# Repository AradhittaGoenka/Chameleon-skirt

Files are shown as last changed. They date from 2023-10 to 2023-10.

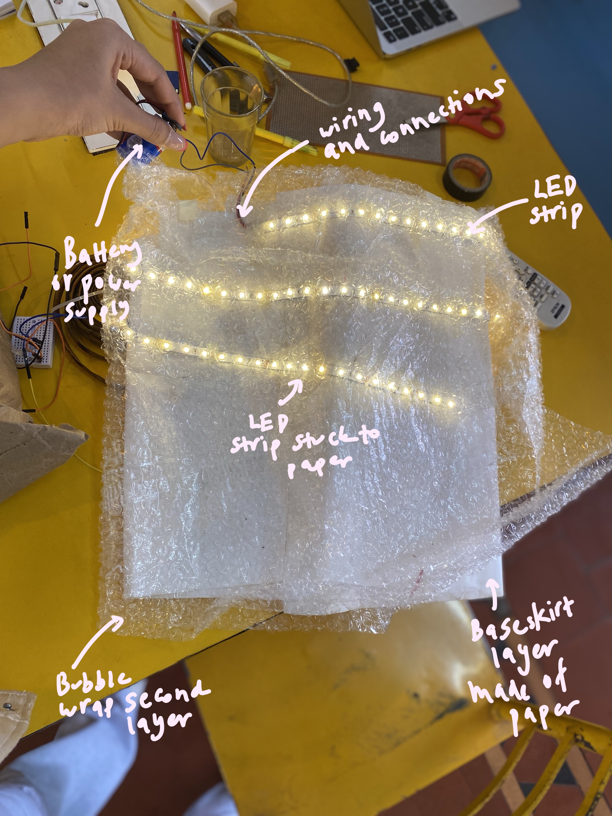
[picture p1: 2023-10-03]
Source files/Images/Labelled paper prototype.jpg

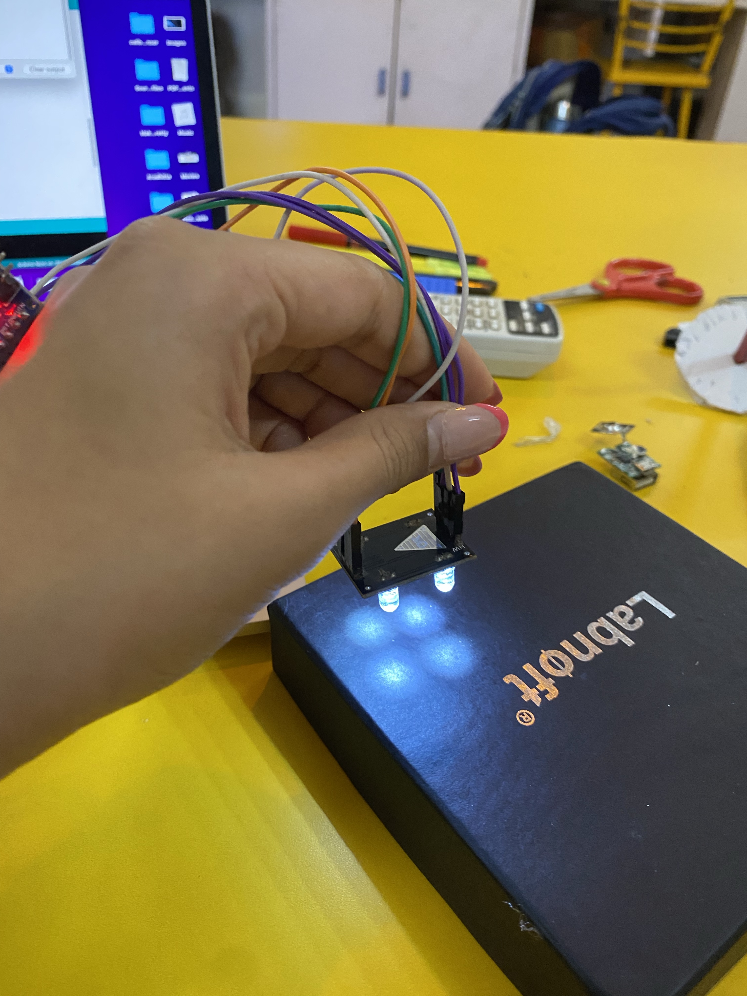
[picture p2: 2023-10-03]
Source files/Images/Colour sensor black calibration.jpg.jpg

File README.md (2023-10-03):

**Spreading joy- A skirt**

**Description:** A fun skirt that changes colour when you hug someone and becomes the colour of their clothing, and lights up in different colours.
Using LEDs that make the skirt light up and a colour sensor to make the skirt change colour!

**Idea:** My idea was to create a fun project that allows you to change the colour of your skirt when you hug someone. I wanted combine fashion and electronics in a fun way that allows people to enjoy and interact with their clothing. Additionally the projects aims to spread love and happiness by encouraging people to hug others and simply make people smile by this simple act.

**Prototypes and rejected versions:**
Problems I faced- my colour sensor needed to be on the outside of the skirt as for it to detect colour it needs to have no obstacles obstructing its view, however, it also has to look nice and the wires or the colour sensor cannot directly be visible. Secondly, the colour sensor needed to be surrounded by some sort of housing so that it did not detect the colour of the skirt itself or have any other interference. My initial models did not have a housing for the colour sensor so the values predicted it by it were not accurate. The RGB strip also needed to be cut and each individual piece soldered to the next which was a time consuming and difficult task. A 12V battery supply was also too large to fit a portable light skirt that you can dance in, but all the long RGB strips were only powered by a 12V power supply. Additionally, I struggled a lot with calibrating my colour sensor and ensuring it can detect the colours in my surroundings.

**Paper prototype:**
For my paper prototype, I wanted to see how I would place the led strip on the skirt, and I wanted to try seeing where all my wiring would go so that it would not hurt the person wearing the skirt and would not be visible. I also wanted to see how I could hide the LED strip so that I could ensure the person wearing it had a fashionable skirt. I thus came up with the idea of having 2 layers for my skirt, the first inner layer where the LED strip was secured and the second outer translucent later that allows the light to pass through while covering the LED strip and also houses the sensor. The bubble wrap does this in the prototype and theres a small inner pocket that houses all the wiring in the skirt.
Solutions and changes: To ensure my colour sensor is on the outside of the skirt and can detect different colours, I came up with the idea of making a second translucent outer layer to my skirt that can hold the colour sensor easily and still look nice. Then to solve the problem of housing my colour sensor I 3d printed a case for my colour sensor that ensures no other colours can interfere with it and affect it. Then to ensure I didn’t have to solder each individual RBG strip to a belt at the top of the skirt, we decided to connect the RBG strips to each other using wires. We also decided that a 9V battery would be good enough to power a 12V RGB strip and it would still glow brightly and be portable.

**Objectives of the project:**
Detect the colour of the surroundings easily
Change the colour of the skirt according to the detected colour of the surroundings Have a skirt that looks cool and changes colour

**Materials: **
Skirt :
A plain straight skirt
An outer translucent skirt
Fabric glue or fevikwik
Thread and a small stiching set, including scissor

LED strip:
10m total RBG LED strip - https://www.amazon.in/Protium-Lights-Multi-Colors-waterproof-Controller/dp/B08YKBRSB4/ref=sr_1_11? crid=3LQOJ6J16MNGD&keywords=rgb+neopixel+led+strip&qid=1696230770&sprefix=rbg+neopixel+led+strip%2Caps%2C191&sr=8-11      
Wires
Soldering iron

Colour sensing:
tcs 3200 colour sensor- https://www.amazon.in/Robodo-Electronics-SEN41-Recognition-Detector/dp/B0787N1L24/ref=sr_1_2? crid=332Y5Y5U4F87S&keywords=colour+sensor+for+arduino&qid=1696230879&sprefix=colour+sensor+%2Caps%2C194&sr=8-2
3d printed and designed enclosure or housing

Power supply:
Rechargeable Batteries (9V)- https://www.amazon.in/Envie-2xC-Size-Rechargeable-Batteries/dp/B00BOLC962/ref=sr_1_1_sspa? crid=8MHD2RY7D6UC&keywords=9v+rechargeable+battery&qid=1696230562&sprefix=9V+rechargeable+batter%2Caps%2C213&sr=8- 1-spons&sp_csd=d2lkZ2V0TmFtZT1zcF9hdGY&psc=1
Charging Module- https://www.amazon.in/Charger-Charge-Control-Rechargeable-Batteries/dp/B0BCG3W4L5/ref=sr_1_1? crid=1IOIABLJQ45KZ&keywords=9v+rechargeable+battery+charger&qid=1696230614&sprefix=9v+rechargeable+battery+cha%2Caps%2C 1
Power Convertor if using less than 9V or if using 5V (the dress will not be portable if this is used

Controller:
Arduino nano - https://www.amazon.in/Maison-Nano-Board-CH340-ATmega328P/dp/B0C1H271SP/ref=sr_1_5? crid=2E5Y3JJTCRWWO&keywords=arduino+nano&qid=1696230648&sprefix=ardui%2Caps%2C207&sr=8-5

**Skills used in the project:**
Throughout the course of this project I learnt a variety of skills and was able to apply a lot of the skills I learnt in both the online and offline sessions at the asylum. I got to work a lot with arduino which helped reinforce all the skills I learnt in the electronics session. I also got to use C while coding the arduino to work and this further strengthened my coding skills. I also worked a lot on my soldering skills which helped me become much better at soldering and more comfortable with all the tools. Additionally, all the CAD sessions were very helpful while designing the case for the colour sensor and I also learnt how to 3d print and design 3d prints. Additionally, all the guidance and support of all our mentors made this project possible and I also learnt many new skills through it like troubleshooting and using a multimeter.
Working of Individual blocks:
The first block was the colour sensor. To test the colour sensor, first you needed to calibrate the colour sensor using a black paper and a white paper. Then once the colour sensor was calibrated we put the minimum and maximum RGB values into the code that runs the colour sensor, this code gave us RGB values. This allowed me to test the colour sensor. We then tried connecting the sensor to an RBG led to see how this was working. The second block was the RGB led strip, this has to be cut to the length of the skirt and then soldered to each other. Then we tested out the working of the strip using a power and supply.

**Logic of the complete program:**
1. When you hug someone, the colour sensor identifies the colour of their clothing and reads the RBG values. 2. These RGB values are then transferred onto the RBG LED strip which changes colour according to this.
3. All the LEDs then change colour and become a certain colour making your dress change colour.
In the end we connected the two blocks to make the final skirt which changes colours, spreading more hugs.
Assembly:
To assemble the skirt, first take the skirt and measure the lengths and distances at which you want to space the led strips. Then cut the LED strips according to the length and cut wires according to the distance between LED strips. Then solder the strips and wires together to form a long connected strip. Then connect the led strip to the arduino and colour sensor and to the power supply. Then stick the strips onto the skirt, and place all the wiring except for the colour sensor in an inner pocket in the skirt. Then place the colour sensor on the center of the outter skirt and stick it there. The skirt is now ready.

**References and sources:**

For inspiration on design and ideas:
https://learn.adafruit.com/florabrella/overview
https://learn.adafruit.com/chameleon-scarf

For help with the code and troubleshooting:
https://dnschecker.org/convert-rgb-to-pantone-pms.php 
https://dronebotworkshop.com/arduino-color-sense/
https://www.youtube.com/watch?v=uczaIETo_Jg 
https://randomnerdtutorials.com/arduino-color-sensor-tcs230-tcs3200/
https://github.com/nthnn/TCS3200

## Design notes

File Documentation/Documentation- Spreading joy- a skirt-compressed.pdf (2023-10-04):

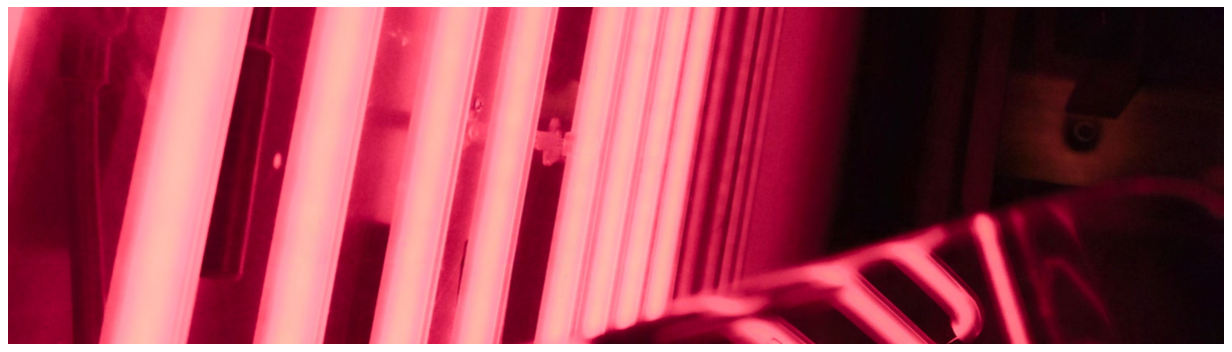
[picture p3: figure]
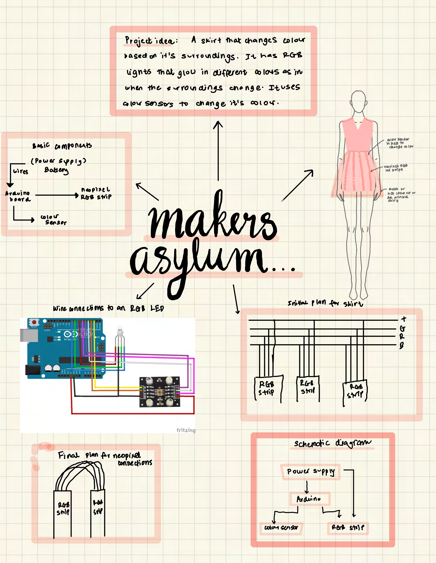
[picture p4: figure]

Documentation- Spreading joy- a skirt | 1

# Documentation- Spreading joy- a skirt

Description: A fun skirt that changes colour when you hug someone and becomes the colour of their clothing, and lights up in different colours. Using LEDs that make the skirt light up and a colour sensor to make the skirt change colour!

Idea: My idea was to create a fun project that allows you to change the colour of your skirt when you hug someone. I wanted combine fashion and electronics in a fun way that allows people to enjoy and interact with their clothing. Additionally the projects aims to spread love and happiness by encouraging people to hug others and simply make people smile by this simple act.

Prototypes and rejected versions:
Problems I faced- my colour sensor needed to be on the outside of the skirt as for it to detect colour it needs to have no obstacles obstructing its view, however, it also has to look nice and the wires or the colour sensor cannot directly be visible. Secondly, the colour sensor needed to be surrounded by some sort of housing so that it did not detect the colour of the skirt itself or have any other interference. My initial models did not have a housing for the colour sensor so the values predicted it by it were not accurate. The RGB strip also needed to be cut and each individual piece soldered to the next which was a time consuming and difficult task. A 12V battery supply was also too large to fit a portable light skirt that you can dance in, but all the long RGB strips were only powered by a 12V power supply. Additionally, I struggled a lot with calibrating my colour sensor and ensuring it can detect the colours in my surroundings.

Ideation and planning my project:

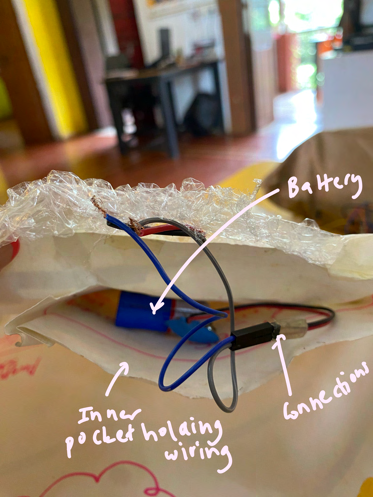
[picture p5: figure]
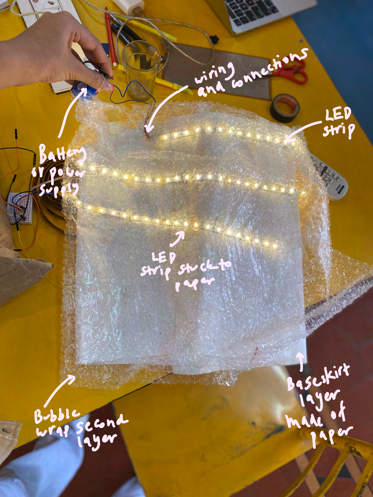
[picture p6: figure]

Documentation- Spreading joy- a skirt | 2

Paper prototype:
For my paper prototype, I wanted to see how I would place the led strip on the skirt, and I wanted to try seeing where all my wiring would go so that it would not hurt the person wearing the skirt and would not be visible. I also wanted to see how I could hide the LED strip so that I could ensure the person wearing it had a fashionable skirt. I thus came up with the idea of having 2 layers for my skirt, the first inner layer where the LED strip was secured and the second outer translucent later that allows the light to pass through while covering the LED strip and also houses the sensor. The bubble wrap does this in the prototype and theres a small inner pocket that houses all the wiring in the skirt.
Inner pocket housing the wiring: | Paper prototype of the skirt
Solutions and changes: | To ensure my colour sensor is on the outside of the skirt and can detect different colours, I came up with the idea of
making a second translucent outer layer to my skirt that can hold the colour sensor easily and still look nice. Then to solve the problem of housing my colour sensor I 3d printed a case for my colour sensor that ensures no other colours can interfere with it and affect it. Then to ensure I didn’t have to solder each individual RBG strip to a belt at the top of the skirt, we decided to connect the RBG strips to each other using wires. We also decided that a 9V battery would be good enough to power a 12V RGB strip and it would still glow brightly and be portable.

Objectives of the project:

Detect the colour of the surroundings easily

Change the colour of the skirt according to the detected colour of the surroundings

Have a skirt that looks cool and changes colour

Block diagram based on objectives

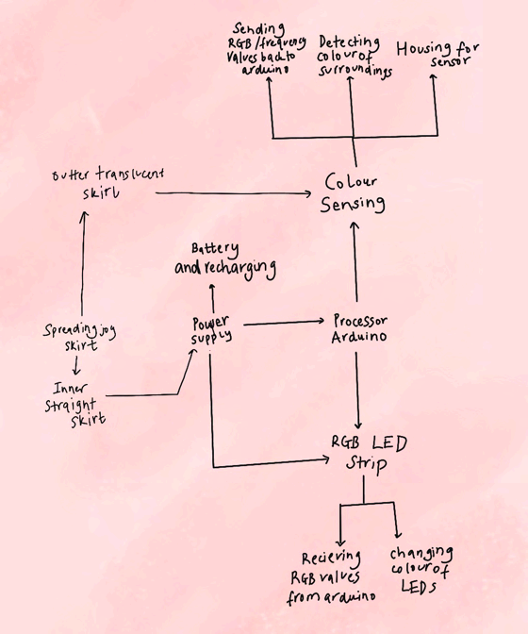
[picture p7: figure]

Documentation- Spreading joy- a skirt | 3

Materials:

Skirt :

A plain straight skirt

An outer translucent skirt

Fabric glue or fevikwik

Thread and a small stiching set, including scissors

LED strip

10m total RBG LED strip - https://www.amazon.in/Protium-Lights-Multi-Colors-waterproof-Controller/dp/B08YKBRSB4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

Wires

Soldering iron

3 NPN transistors

Colour sensing

tcs 3200 colour sensor- https://www.amazon.in/Robodo-Electronics-SEN41-Recognition-Detector/dp/B0787N1L24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

3d printed and designed enclosure or housing

Power supply

Rechargeable Batteries (9V)- https://www.amazon.in/Envie-2xC-Size-Rechargeable-Batteries/dp/B00BOLC962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

Charging Module- https://www.amazon.in/Charger-Charge-Control-Rechargeable-Batteries/dp/B0BCG3W4L5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 1

Power Convertor if using less than 9V or if using 5V (the dress will not be portable if this is used

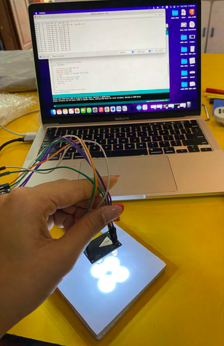
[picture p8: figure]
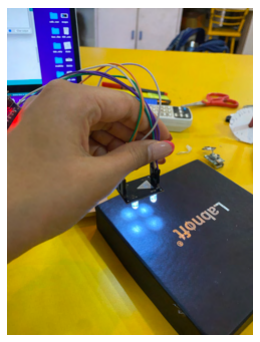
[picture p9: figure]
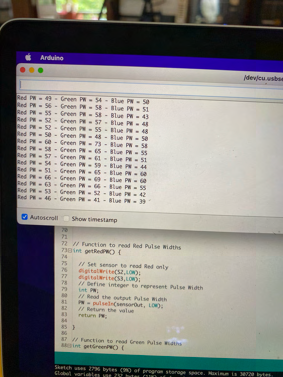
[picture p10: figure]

Documentation- Spreading joy- a skirt | 4

Controller

Arduino nano - https://www.amazon.in/Maison-Nano-Board-CH340-ATmega328P/dp/B0C1H271SP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

Skills used in the project:

Throughout the course of this project I learnt a variety of skills and was able to apply a lot of the skills I learnt in both the online and offline sessions at the asylum. I got to work a lot with arduino which helped reinforce all the skills I learnt in the electronics session. I also got to use C while coding the arduino to work and this further strengthened my coding skills. I also worked a lot on my soldering skills which helped me become much better at soldering and more comfortable with all the tools. Additionally, all the CAD sessions were very helpful while designing the case for the colour sensor and I also learnt how to 3d print and design 3d prints. Additionally, all the guidance and support of all our mentors made this project possible and I also learnt many new skills through it like troubleshooting and using a multimeter.

Working of Individual blocks:
The first block was the colour sensor. To test the colour sensor, first you needed to calibrate the colour sensor using a black paper and a white paper. Then once the colour sensor was calibrated we put the minimum and maximum RGB values into the code that runs the colour sensor, this code gave us RGB values. This allowed me to test the colour sensor. We then tried connecting the sensor to an RBG led to see how this was working.

Calibrating the colour sensor:

The circuit of the arduino, colour sensor and RGB LED

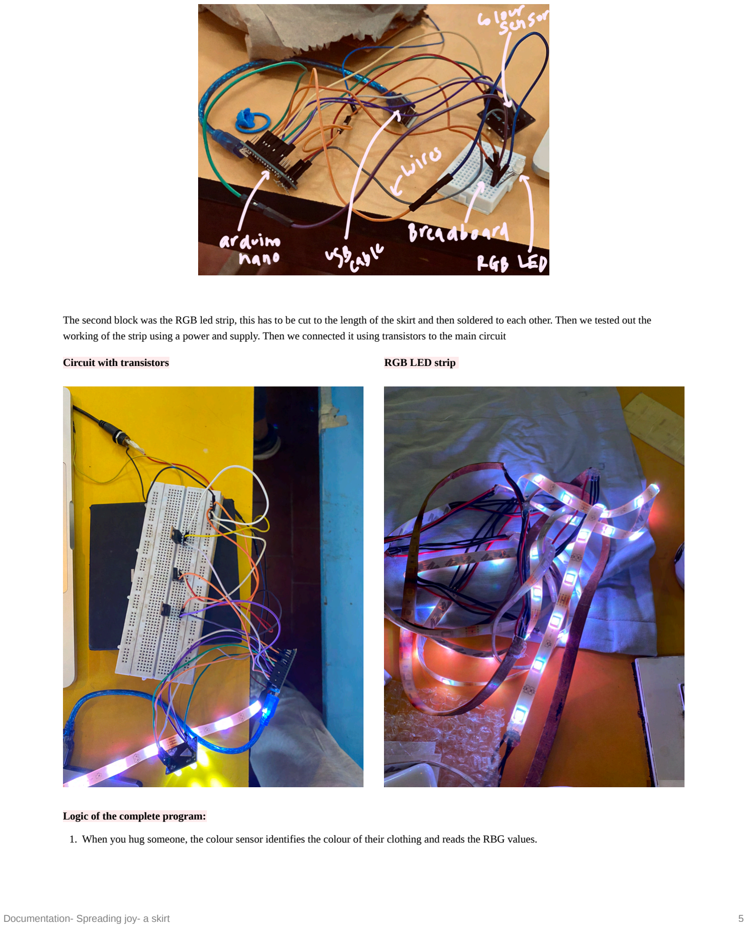
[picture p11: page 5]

Documentation- Spreading joy- a skirt | 5

The second block was the RGB led strip, this has to be cut to the length of the skirt and then soldered to each other. Then we tested out the working of the strip using a power and supply. Then we connected it using transistors to the main circuit

Circuit with transistors | RGB LED strip

Logic of the complete program:

1. When you hug someone, the colour sensor identifies the colour of their clothing and reads the RBG values.

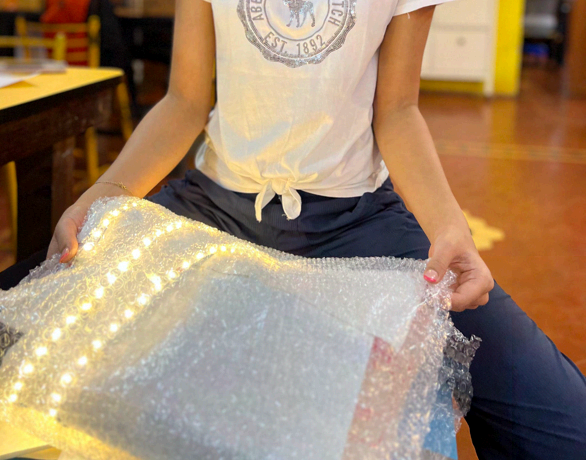
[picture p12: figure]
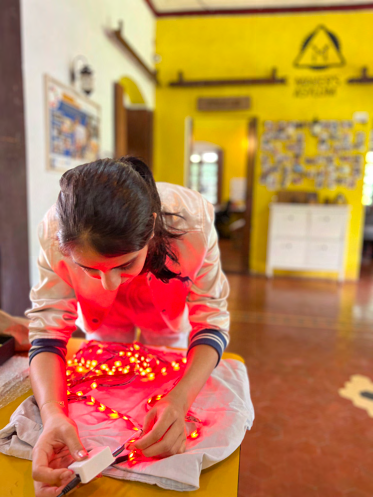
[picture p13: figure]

Documentation- Spreading joy- a skirt | 6
2. These RGB values are then transferred onto the RBG LED strip which changes colour according to this.
3. All the LEDs then change colour and become a certain colour making your dress change colour.

In the end we connected the two blocks to make the final skirt which changes colours, spreading more hugs.

Prototype of the model and the final skirt lighting up and being connected to the power supply

Assembly:

To assemble the skirt, first take the skirt and measure the lengths and distances at which you want to space the led strips. Then cut the LED strips according to the length and cut wires according to the distance between LED strips. Then solder the strips and wires together to form a long connected strip. Then connect the led strip to the arduino and colour sensor and to the power supply. Then stick the strips onto the skirt, and place all the wiring except for the colour sensor in an inner pocket in the skirt. Then place the colour sensor on the center of the outter skirt and stick it there. The skirt is now ready.

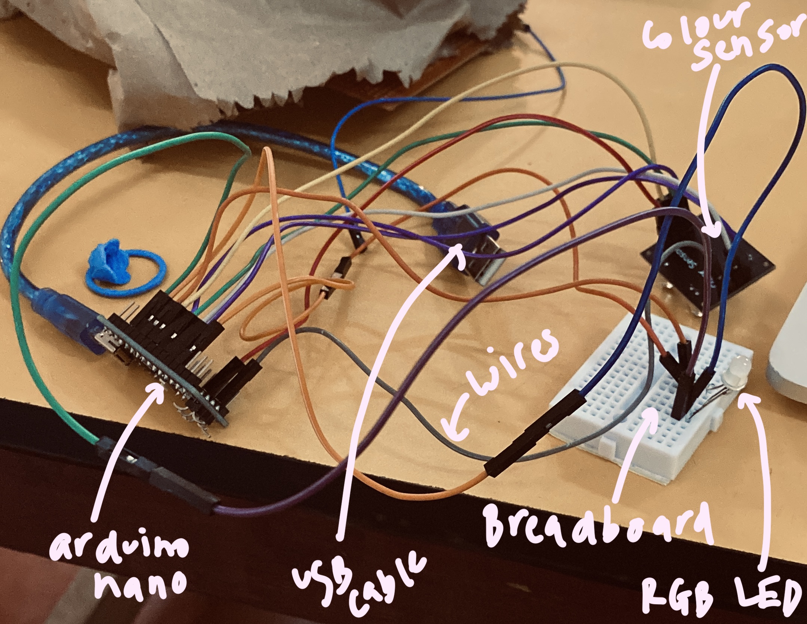
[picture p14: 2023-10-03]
Source files/Images/Circuit for colour sensor with RGB LED.jpg

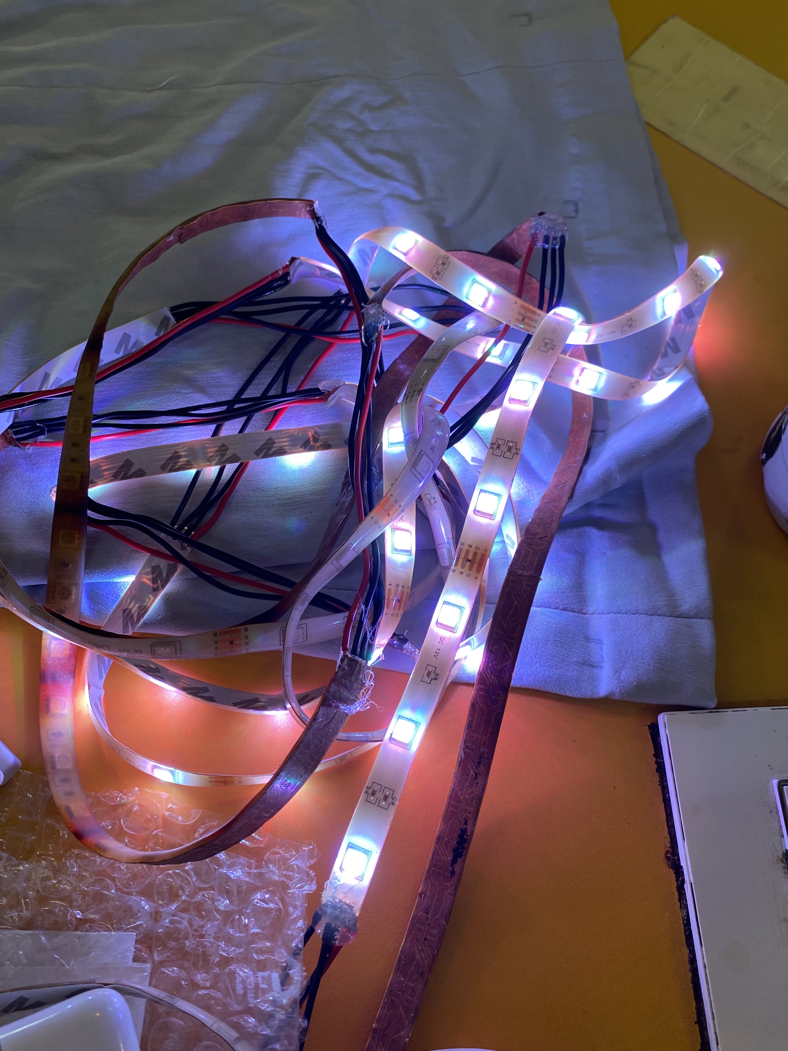
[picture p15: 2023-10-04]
Source files/Images/RGB led glowing.jpg

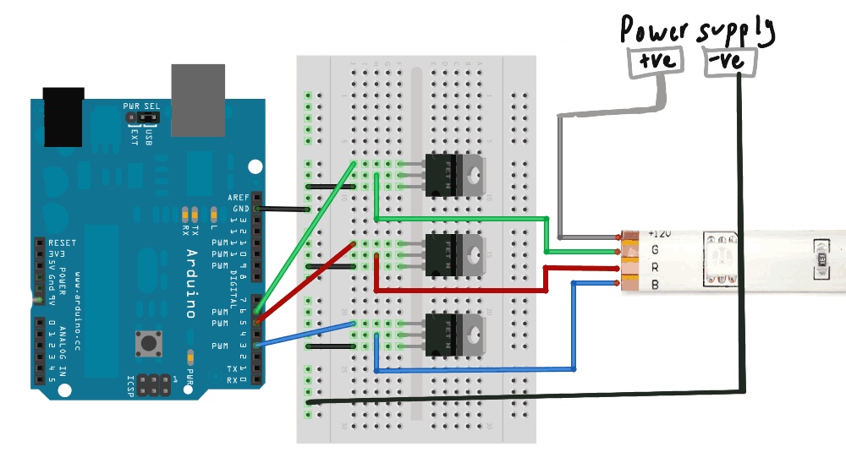
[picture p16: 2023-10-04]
Source files/Images/Circuit for RGB LED.jpg

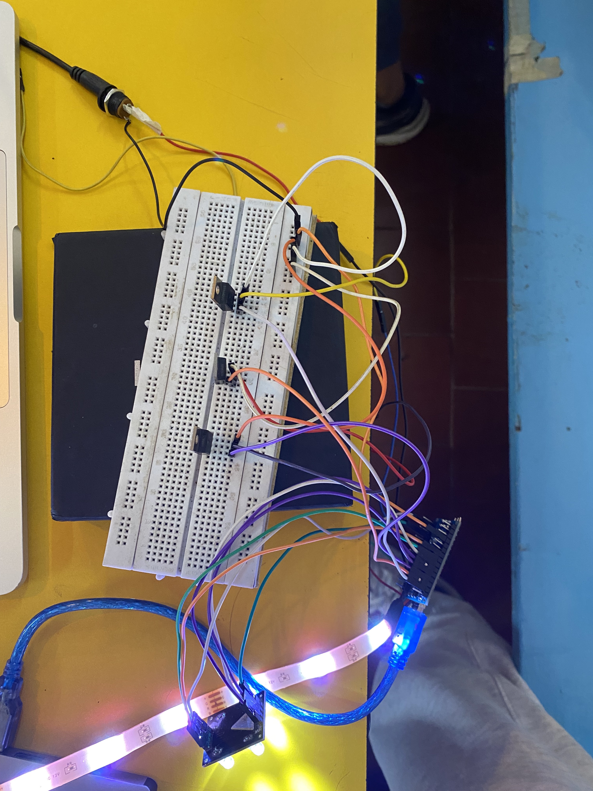
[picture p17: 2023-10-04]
Source files/Images/final circuit connections.jpg

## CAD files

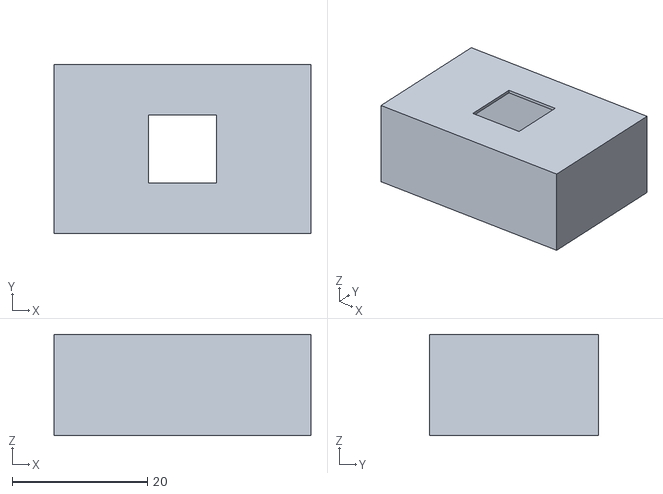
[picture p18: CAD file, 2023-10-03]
Source files/CAD/Design for housing of colour sensor.stl
38.0 x 25.0 x 15.0

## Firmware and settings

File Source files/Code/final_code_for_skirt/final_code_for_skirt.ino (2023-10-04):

/*
  RGB Color Sensor Demonstration
  rgb-color-sensor-demo.ino
  Read RGB values from Color Sensor
  Must use calibration values from Color Sensor Calibration Sketch

  DroneBot Workshop 2020
  https://dronebotworkshop.com
*/

// Define color sensor pins

#define S0 4
#define S1 5
#define S2 6
#define S3 7
#define sensorOut 8
#define Rpin 10
#define Gpin 9
#define Bpin 11
// Calibration Values
// Get these from Calibration Sketch

int redMin = 45; // Red minimum value
int redMax = 306; // Red maximum value
int greenMin = 42; // Green minimum value
int greenMax = 340; // Green maximum value
int blueMin = 36; // Blue minimum value
int blueMax = 285; // Blue maximum value

// Variables for Color Pulse Width Measurements

int redPW = 0;
int greenPW = 0;
int bluePW = 0;

// Variables for final Color values

int redValue;
int greenValue;
int blueValue;

void setup() {

  // Set S0 - S3 as outputs
  pinMode(S0, OUTPUT);
  pinMode(S1, OUTPUT);
  pinMode(S2, OUTPUT);
  pinMode(S3, OUTPUT);
  pinMode(Rpin, OUTPUT);
  pinMode(Gpin, OUTPUT);
  pinMode(Bpin, OUTPUT);
  // Set Sensor output as input
  pinMode(sensorOut, INPUT);
  
  // Set Frequency scaling to 20%
  digitalWrite(S0,HIGH);
  digitalWrite(S1,LOW);
  
  // Setup Serial Monitor
  Serial.begin(9600);
}

void loop() {
  
  // Read Red value
  redPW = getRedPW();
  // Map to value from 0-255
  redValue = map(redPW, redMin,redMax,255,0);
  // Delay to stabilize sensor
  delay(200);
  
  // Read Green value
  greenPW = getGreenPW();
  // Map to value from 0-255
  greenValue = map(greenPW, greenMin,greenMax,255,0);
  // Delay to stabilize sensor
  delay(200);
  
  // Read Blue value
  bluePW = getBluePW();
  // Map to value from 0-255
  blueValue = map(bluePW, blueMin,blueMax,255,0);
  // Delay to stabilize sensor
  delay(200);
  
  // Print output to Serial Monitor
  Serial.println("Red = ");
  Serial.print(redValue);
  Serial.println("Green = ");
  Serial.print(greenValue);
  Serial.println("Blue = ");
  Serial.print(blueValue);
  analogWrite(Rpin,redValue);
  analogWrite(Gpin,greenValue);
  analogWrite(Bpin,blueValue); 
}


// Function to read Red Pulse Widths
int getRedPW() {

  // Set sensor to read Red only
  digitalWrite(S2,LOW);
  digitalWrite(S3,LOW);
  // Define integer to represent Pulse Width
  int PW;
  // Read the output Pulse Width
  PW = pulseIn(sensorOut, LOW);
  // Return the value
  return PW;

}

// Function to read Green Pulse Widths
int getGreenPW() {

  // Set sensor to read Green only
  digitalWrite(S2,HIGH);
  digitalWrite(S3,HIGH);
  // Define integer to represent Pulse Width
  int PW;
  // Read the output Pulse Width
  PW = pulseIn(sensorOut, LOW);
  // Return the value
  return PW;

}

// Function to read Blue Pulse Widths
int getBluePW() {

  // Set sensor to read Blue only
  digitalWrite(S2,LOW);
  digitalWrite(S3,HIGH);
  // Define integer to represent Pulse Width
  int PW;
  // Read the output Pulse Width
  PW = pulseIn(sensorOut, LOW);
  // Return the value
  return PW;

}
